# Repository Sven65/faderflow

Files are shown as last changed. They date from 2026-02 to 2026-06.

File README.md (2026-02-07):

# faderflow

> Fluid control over your desktop audio

A hardware audio mixer with motorized faders, full-color displays, and automatic application detection.



## Features

- 🎛️ 5 motorized faders with position sensing
- 🖥️ 5x 1.54" color TFT displays (240x240)
- 🔄 Bidirectional sync between hardware and Windows
- 🎯 Automatic app detection
- 📄 Multi-page navigation
- 💾 SD card icon storage

## Hardware

- Arduino Mega 2560
- 5x Behringer X32 Motorized Faders
- 3x DRV8833 Motor Driver Boards
- 6x ST7789 TFT Displays (1.54", 240x240)
- 6x EC11 Rotary Encoders
- SD Card Module
- USB-C PD Power (5V 3A)

## Software Stack

- **Desktop:** Rust + iced
- **Firmware:** Arduino C++
- **Platform:** Windows (Linux planned)

## Quick Start
```bash
# Clone repo
git clone https://github.com/Sven65/faderflow.git

# Build desktop app
cd desktop
cargo build --release

# Flash firmware
# Open firmware/faderflow/faderflow.ino in Arduino IDE
```

## Status

🚧 **Work in Progress** - Hardware picked out, software in development

## License

MIT License - see [LICENSE](LICENSE)

## Acknowledgments

Inspired by [deej](https://github.com/omriharel/deej)

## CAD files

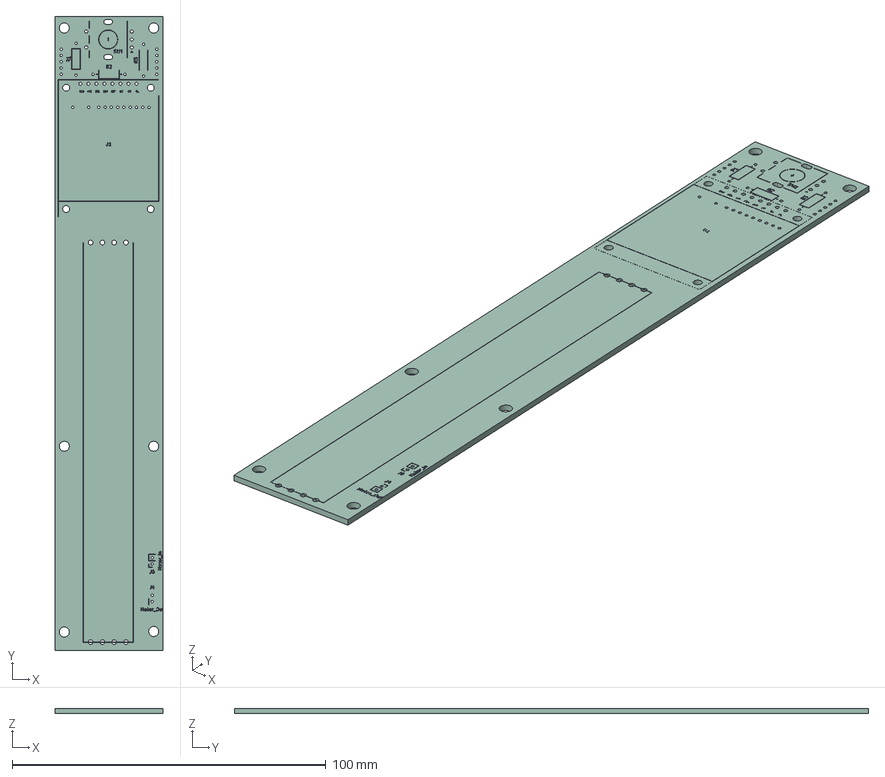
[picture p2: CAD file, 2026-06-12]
pcb/Channel/Channel.step
34.5 x 202.0 x 1.66 mm
Channel_silkscreen
Channel_PCB

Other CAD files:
pcb/Channel/Channel.stl

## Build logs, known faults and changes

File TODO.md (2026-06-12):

# FaderFlow - Project TODO

## ✅ Phase 0: Foundation (DONE)
- [x] Basic Iced UI setup
- [x] Windows audio session enumeration
- [x] Volume control (bidirectional sync)
- [x] Mute control (bidirectional sync)
- [x] App icon extraction
- [x] Cross-platform architecture (trait-based backend)
- [x] COM callback system for external changes
- [x] Batch processing to prevent UI jitter

## 🔨 Phase 1: Complete Audio Backend
- [ ] **Device Management**
    - [ ] Enumerate all audio output devices
    - [ ] Track which device each session is using (read-only for now)
    - [ ] Display device name in UI
    - [ ] System-wide default device switching
    - [ ] Detect when devices are plugged/unplugged

- [ ] **Session Management**
    - [ ] Handle sessions appearing/disappearing smoothly
    - [ ] Persist session-to-channel mappings
    - [ ] Auto-assign new sessions to free channels
    - [ ] Handle duplicate app names (Chrome tab 1, 2, 3...)

- [ ] **UI Polish**
    - [ ] Better layout (grid view for channels)
    - [ ] Visual feedback for which device is active
    - [ ] Session search/filter
    - [ ] Master volume control
    - [ ] System tray integration
    - [ ] Minimize to tray

## 🔌 Phase 2: Hardware Protocol
- [ ] **Serial Communication**
    - [ ] Define protocol format (JSON? Binary? MessagePack?)
    - [ ] Implement serial port detection/connection
    - [ ] Send motor position commands
        - [ ] Protocol: `MOTOR <channel> <position_0-100>`
    - [ ] Send screen update commands
        - [ ] Protocol: `SCREEN <channel> <icon_data> <name> <volume%>`
    - [ ] Receive fader position updates
        - [ ] Protocol: `FADER <channel> <position_0-100>`
    - [ ] Receive knob rotation updates
        - [ ] Protocol: `KNOB <channel> <delta>`

- [ ] **Motor Sync**
    - [ ] When Windows volume changes → move motor
    - [ ] Smooth motor movements (acceleration curves)
    - [ ] Handle motor conflicts (user moving while motor moves)
    - [ ] Calibration routine on startup

- [ ] **Screen Updates**
    - [ ] Convert icons to format your displays need (resolution, color depth)
    - [ ] Optimize icon transfer (only send when changed)
    - [ ] Handle missing icons (default placeholder)
    - [ ] Show volume percentage and mute status on screen

## 📊 Phase 3: Profile System
- [ ] **Profile Management**
    - [ ] Create profile structure (JSON config file?)
    - [ ] Save profiles: `profiles/<device_name>.json`
    - [ ] Profile contents:
        - [ ] Channel assignments (which app on which fader)
        - [ ] Custom names/colors per channel
        - [ ] Master volume settings
    - [ ] Auto-switch profile when output device changes
    - [ ] UI for creating/editing/deleting profiles
    - [ ] Import/export profiles

- [ ] **Channel Mapping**
    - [ ] Assign specific apps to specific channels
    - [ ] Wildcard matching (e.g., "chrome*" → channel 1)
    - [ ] Priority system (if multiple apps match)
    - [ ] "Unmapped apps" overflow handling

## 🎛️ Phase 4: Advanced Features
- [ ] **Per-App Audio Routing** (HARD)
    - [ ] Research options:
        - [ ] Study SoundSwitch source code
        - [ ] Study AudioRouter source code
        - [ ] Investigate IPolicyConfig COM interface
        - [ ] Consider app restart approach
    - [ ] Choose implementation strategy
    - [ ] Implement device switching
    - [ ] Handle edge cases (apps that don't respond)

- [ ] **Hotkeys**
    - [ ] Global hotkey support
    - [ ] Toggle mute for specific apps
    - [ ] Quick profile switching
    - [ ] Push-to-talk style muting

- [ ] **Advanced UI**
    - [ ] Dark/light theme
    - [ ] Customizable colors per channel
    - [ ] Visualizers (audio level meters)
    - [ ] Mini mode (compact overlay)
    - [ ] Always-on-top option

## 🐧 Phase 5: Cross-Platform (Future)
- [ ] **Linux Support**
    - [ ] PulseAudio backend implementation
    - [ ] PipeWire backend (modern Linux)
    - [ ] Icon extraction for Linux
    - [ ] Test on various distros

- [ ] **macOS Support** (maybe?)
    - [ ] CoreAudio backend implementation
    - [ ] Icon extraction for macOS
    - [ ] Handle macOS sandboxing/permissions

## 🔧 Phase 6: Polish & Release
- [ ] **Testing**
    - [ ] Test with many simultaneous apps
    - [ ] Test device hotplug scenarios
    - [ ] Test with different audio hardware
    - [ ] Memory leak testing (COM cleanup)
    - [ ] Long-running stability test

- [ ] **Documentation**
    - [ ] User guide
    - [ ] Hardware build guide
    - [ ] Protocol documentation
    - [ ] Firmware examples for Arduino/ESP32
    - [ ] Troubleshooting guide

- [ ] **Distribution**
    - [ ] Windows installer
    - [ ] Auto-updater
    - [ ] GitHub releases
    - [ ] AUR package (for Arch Linux)

## 🎯 Current Sprint
**Focus: Complete Phase 1 - Audio Backend**

### This Week:
1. Finish device enumeration in UI
2. Add device picker dropdown (read-only for now)
3. Implement session persistence between app restarts
4. Add system tray icon

### Next Week:
1. Start hardware protocol design
2. Set up serial communication testing
3. Mock hardware for development (simulate with keyboard?)

---

## Notes & Ideas
- Consider using `egui` instead of `iced` if you need faster iteration?
- Look into Windows MIDI API for ultra-low-latency control?
- Could add OBS integration (control audio sources)?
- Discord/TeamSpeak integration for per-person volume?
- Game detection (auto-load "Gaming" profile)?
- Time-based profiles (work hours vs evening)?

---

## Hardware Waiting On:
- [ ] Motorized faders (ordered)
- [ ] Screens (TFT? OLED? e-ink?)
- [ ] Rotary encoders for knobs
- [ ] Microcontroller (Arduino? ESP32? Teensy?)
- [ ] Case/enclosure design

---

**Keep this updated as you go!** 🚀

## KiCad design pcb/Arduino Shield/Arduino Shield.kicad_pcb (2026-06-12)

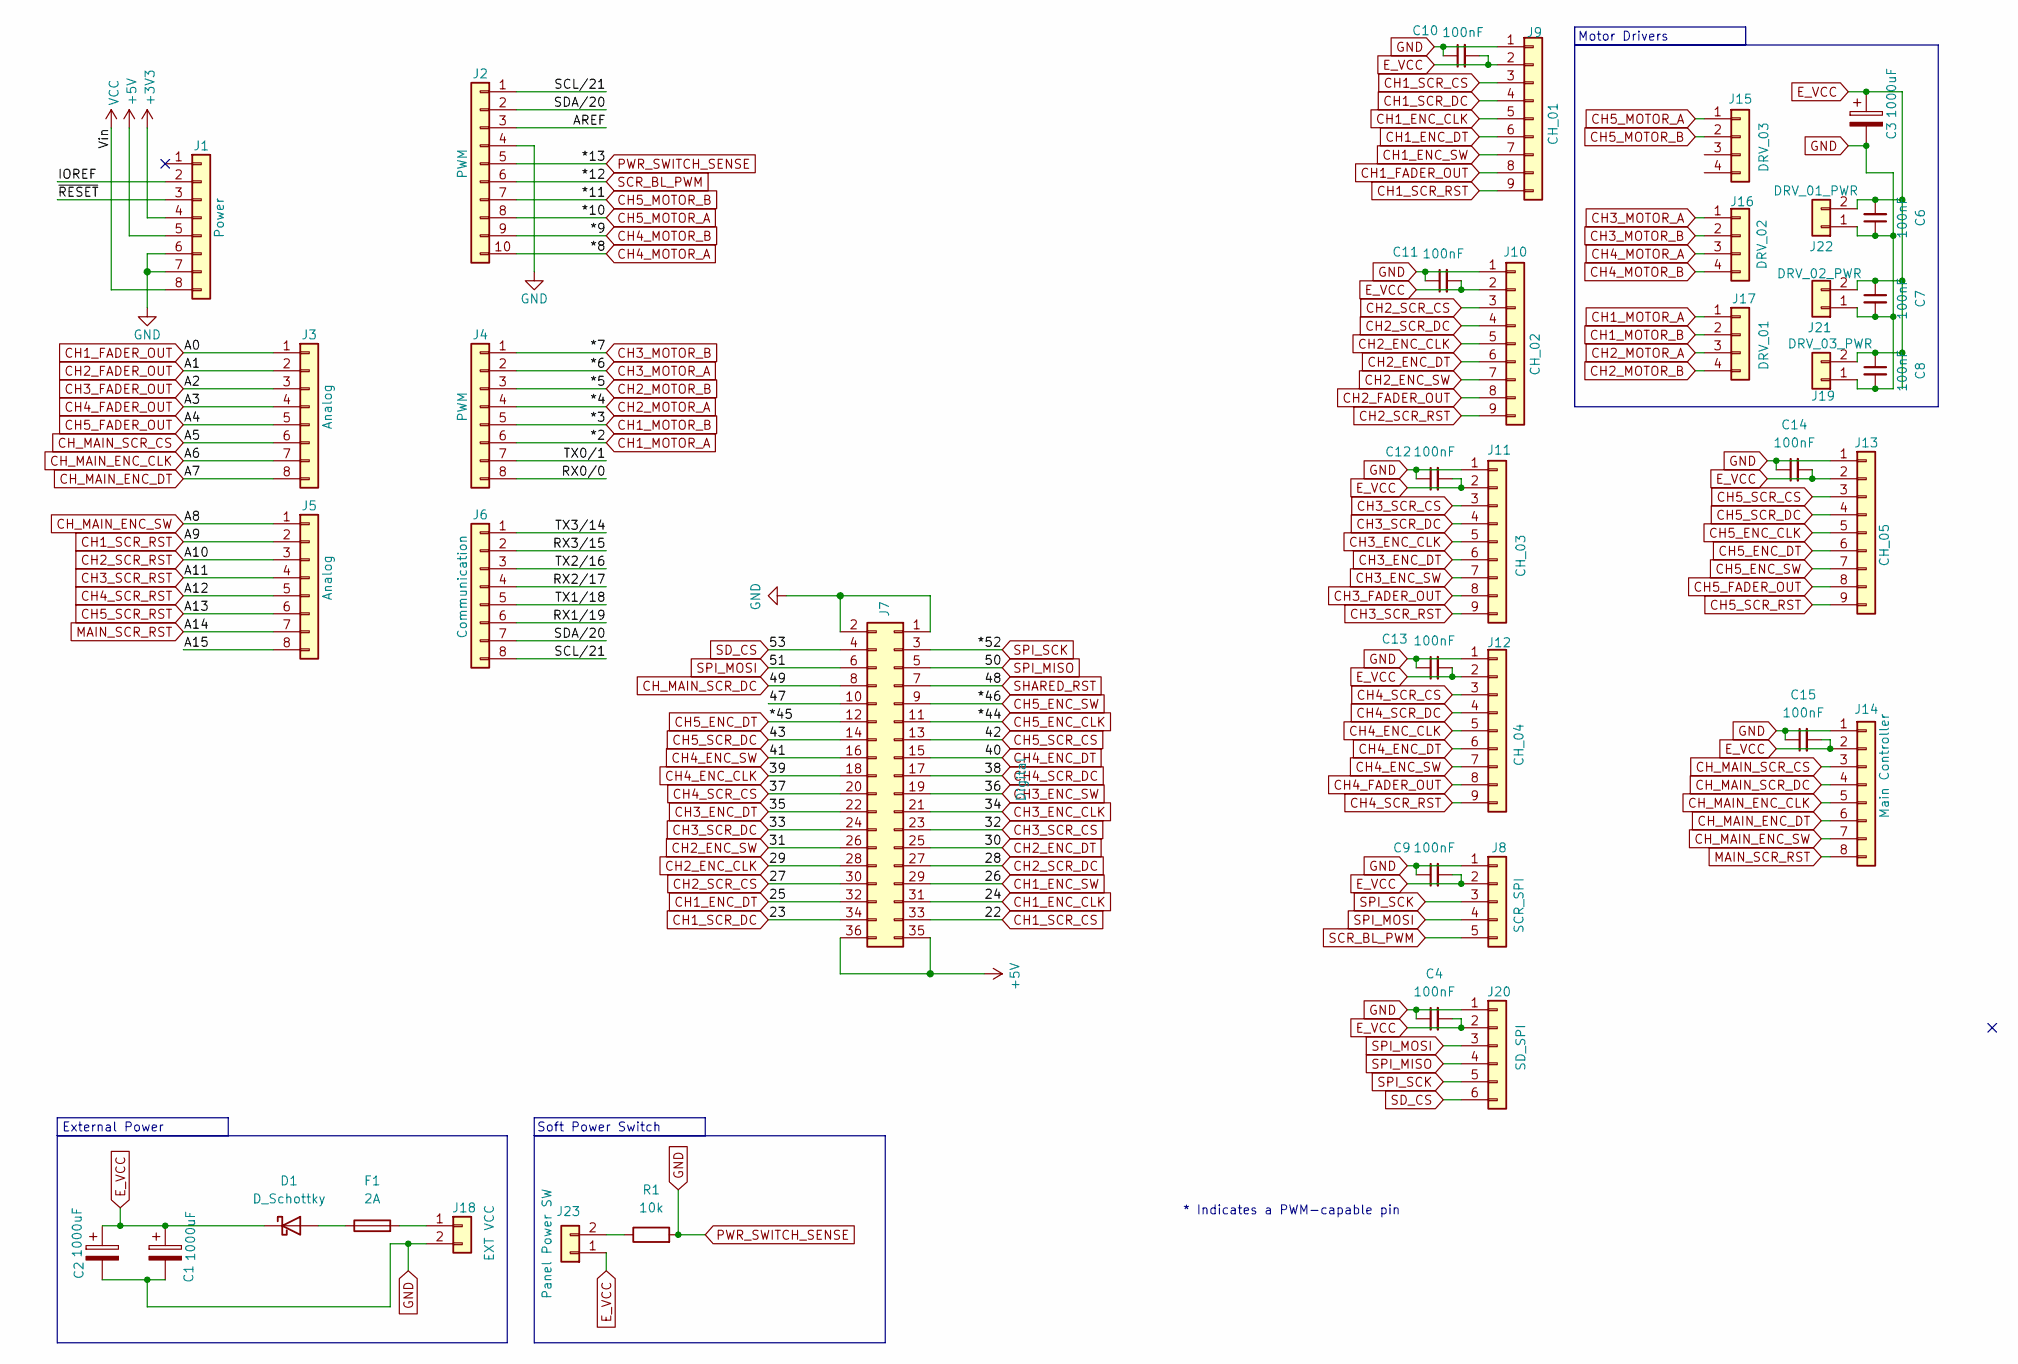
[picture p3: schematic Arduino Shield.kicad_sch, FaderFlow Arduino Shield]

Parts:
C1, C2, C3: 1000uF; CP_Radial_D8.0mm_P3.50mm
C4, C6, C7, C8, C9, C10, C11, C12, C13, C14, C15: 100nF; C_Disc_D5.0mm_W2.5mm_P5.00mm
D1: D_Schottky; D_DO-201AD_P15.24mm_Horizontal
F1: 2A; Fuseholder_Clip-5x20mm_Eaton_1A5601-01_Inline_P20.80x6.76mm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
J1: Power; PinSocket_1x08_P2.54mm_Vertical
J2: PWM; PinSocket_1x10_P2.54mm_Vertical
J3, J5: Analog; PinSocket_1x08_P2.54mm_Vertical
J4: PWM; PinSocket_1x08_P2.54mm_Vertical
J6: Communication; PinSocket_1x08_P2.54mm_Vertical
J7: Digital; PinSocket_2x18_P2.54mm_Vertical
J8: SCR_SPI; PinSocket_1x05_P2.00mm_Vertical
J9: CH_01; PinSocket_1x09_P2.00mm_Vertical
J10: CH_02; PinSocket_1x09_P2.00mm_Vertical
J11: CH_03; PinSocket_1x09_P2.00mm_Vertical
J12: CH_04; PinSocket_1x09_P2.00mm_Vertical
J13: CH_05; PinSocket_1x09_P2.00mm_Vertical
J14: Main Controller; PinSocket_1x08_P2.00mm_Vertical
J15: DRV_03; PinSocket_1x04_P2.00mm_Vertical
J16: DRV_02; PinSocket_1x04_P2.00mm_Vertical
J17: DRV_01; PinSocket_1x04_P2.00mm_Vertical
J18: EXT VCC; PinSocket_1x02_P2.00mm_Vertical
J19: DRV_03_PWR; PinSocket_1x02_P2.00mm_Vertical
J20: SD_SPI; PinSocket_1x06_P2.00mm_Vertical
J21: DRV_02_PWR; PinSocket_1x02_P2.00mm_Vertical
J22: DRV_01_PWR; PinSocket_1x02_P2.00mm_Vertical
J23: Panel Power SW; PinSocket_1x02_P2.00mm_Vertical
R1: 10k; R_Axial_DIN0207_L6.3mm_D2.5mm_P10.16mm_Horizontal

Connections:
+3V3: J1.4
+5V: J1.5, J7.35, J7.36
/47: J7.10
/A15: J5.8
/AREF: J2.3
/IOREF: J1.2
/RX0/0: J4.8
/RX1/19: J6.6
/RX2/17: J6.4
/RX3/15: J6.2
/SCL/21: J2.1, J6.8
/SDA/20: J2.2, J6.7
/TX0/1: J4.7
/TX1/18: J6.5
/TX2/16: J6.3
/TX3/14: J6.1
/~RESET: J1.3
CH1_ENC_CLK: J7.31, J9.5
CH1_ENC_DT: J7.32, J9.6
CH1_ENC_SW: J7.29, J9.7
CH1_FADER_OUT: J3.1, J9.8
CH1_MOTOR_A: J4.6, J17.1
CH1_MOTOR_B: J4.5, J17.2
CH1_SCR_CS: J7.33, J9.3
CH1_SCR_DC: J7.34, J9.4
CH1_SCR_RST: J5.2, J9.9
CH2_ENC_CLK: J7.28, J10.5
CH2_ENC_DT: J7.25, J10.6
CH2_ENC_SW: J7.26, J10.7
CH2_FADER_OUT: J3.2, J10.8
CH2_MOTOR_A: J4.4, J17.3
CH2_MOTOR_B: J4.3, J17.4
CH2_SCR_CS: J7.30, J10.3
CH2_SCR_DC: J7.27, J10.4
CH2_SCR_RST: J5.3, J10.9
CH3_ENC_CLK: J7.21, J11.5
CH3_ENC_DT: J7.22, J11.6
CH3_ENC_SW: J7.19, J11.7
CH3_FADER_OUT: J3.3, J11.8
CH3_MOTOR_A: J4.2, J16.1
CH3_MOTOR_B: J4.1, J16.2
CH3_SCR_CS: J7.23, J11.3
CH3_SCR_DC: J7.24, J11.4
CH3_SCR_RST: J5.4, J11.9
CH4_ENC_CLK: J7.18, J12.5
CH4_ENC_DT: J7.15, J12.6
CH4_ENC_SW: J7.16, J12.7
CH4_FADER_OUT: J3.4, J12.8
CH4_MOTOR_A: J2.10, J16.3
CH4_MOTOR_B: J2.9, J16.4
CH4_SCR_CS: J7.20, J12.3
CH4_SCR_DC: J7.17, J12.4
CH4_SCR_RST: J5.5, J12.9
CH5_ENC_CLK: J7.11, J13.5
CH5_ENC_DT: J7.12, J13.6
CH5_ENC_SW: J7.9, J13.7
CH5_FADER_OUT: J3.5, J13.8
CH5_MOTOR_A: J2.8, J15.1
CH5_MOTOR_B: J2.7, J15.2
CH5_SCR_CS: J7.13, J13.3
CH5_SCR_DC: J7.14, J13.4
CH5_SCR_RST: J5.6, J13.9
CH_MAIN_ENC_CLK: J3.7, J14.5
CH_MAIN_ENC_DT: J3.8, J14.6
CH_MAIN_ENC_SW: J5.1, J14.7
CH_MAIN_SCR_CS: J3.6, J14.3
CH_MAIN_SCR_DC: J7.8, J14.4
E_VCC: C1.1, C2.1, C3.1, C4.2, C6.2, C7.1, C8.1, C9.2, C10.2, C11.2, C12.2, C13.2, C14.2, C15.2, D1.1 (K), J8.2, J9.2, J10.2, J11.2, J12.2, J13.2, J14.2, J19.2, J20.2, J21.2, J22.2, J23.1
GND: C1.2, C2.2, C3.2, C4.1, C6.1, C7.2, C8.2, C9.1, C10.1, C11.1, C12.1, C13.1, C14.1, C15.1, J1.6, J1.7, J2.4, J2.5, J7.1, J7.2, J8.1, J9.1, J10.1, J11.1, J12.1, J13.1, J14.1, J18.2, J19.1, J20.1, J21.1, J22.1, R1.2
MAIN_SCR_RST: J5.7, J14.8
unnamed: D1.2 (A), F1.1
unnamed: F1.2, J18.1
unnamed: J23.2, R1.1
SCR_BL_PWM: J2.6, J8.5
SD_CS: J7.4, J20.6
SHARED_RST: J7.7
SPI_MISO: J7.5, J20.4
SPI_MOSI: J7.6, J8.4, J20.3
SPI_SCK: J7.3, J8.3, J20.5
VCC: J1.8

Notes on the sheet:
External Power
Soft Power Switch
Motor Drivers
* Indicates a PWM-capable pin

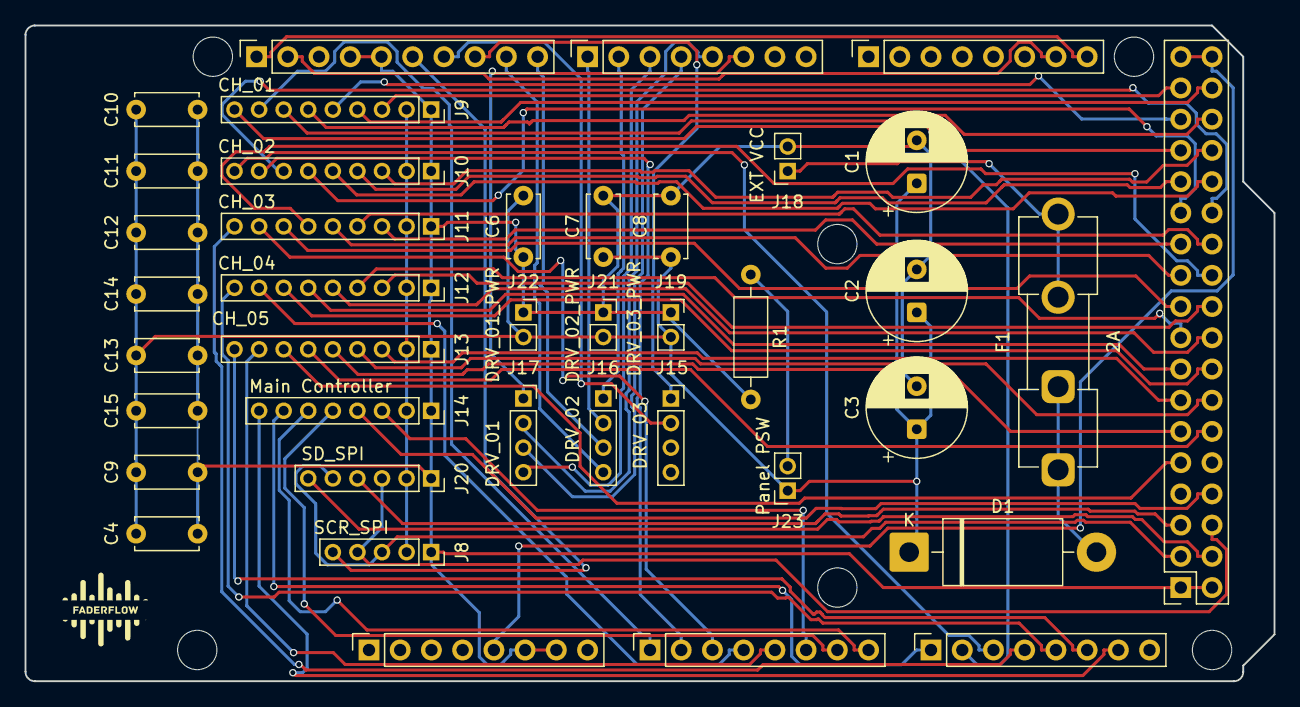
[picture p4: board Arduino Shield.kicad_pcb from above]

Board: 2 copper layers, 101.6 x 53.3 mm, 46 parts (0 on the bottom side), 64 nets.

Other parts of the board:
MH1, MH2, MH3, MH4, MH5, MH6: MountingHole_3.2mm

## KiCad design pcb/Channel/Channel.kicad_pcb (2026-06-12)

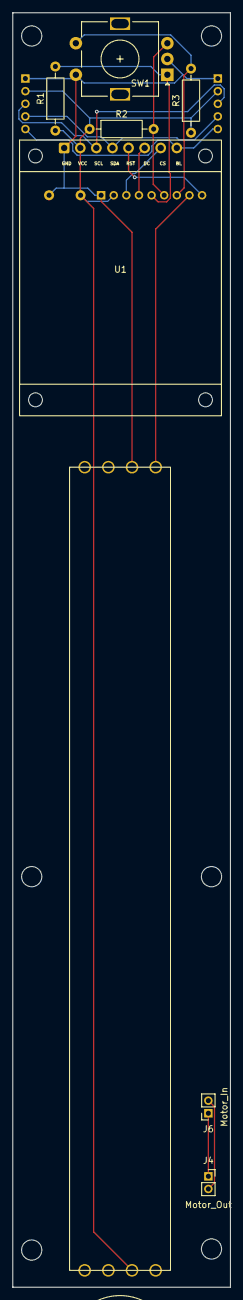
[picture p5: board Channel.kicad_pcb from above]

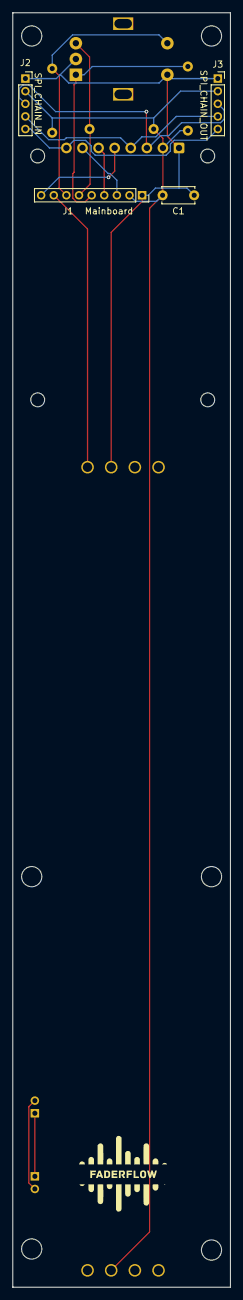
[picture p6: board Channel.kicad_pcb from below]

Board: 2 copper layers, 34.5 x 202.0 mm, 18 parts (4 on the bottom side), 14 nets.

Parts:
C1: 0.1uF; C_Disc_D5.0mm_W2.5mm_P5.00mm
F1: Behringer X32 Fader
J1: Mainboard; PinSocket_1x09_P2.00mm_Vertical
J2: SPI_CHAIN_IN; PinSocket_1x05_P2.00mm_Vertical
J3: SPI_CHAIN_OUT; PinSocket_1x05_P2.00mm_Vertical
J4: Motor_Out; PinSocket_1x02_P2.00mm_Vertical
J6: Motor_In; PinSocket_1x02_P2.00mm_Vertical
Mount_1, Mount_2, Mount_3, Mount_4, Mount_6, Mount_7: MountingHole_3.2mm_M3
R1, R2, R3: 10k; R_Axial_DIN0207_L6.3mm_D2.5mm_P10.16mm_Horizontal
SW1: RotaryEncoder_Switch; RotaryEncoder_Alps_EC11E-Switch_Vertical_H20mm
U1: 1.54 inch

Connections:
ENC_CLK: J1.5, R1.2, SW1.A
ENC_DT: J1.6, R2.2, SW1.B
ENC_SW: J1.7, R3.2, SW1.S1
E_VCC: C1.2, F1.3 (T2), J1.2, J2.2, J3.2, R1.1, R2.1, R3.1, U1.2 (VCC)
FADER_OUT: F1.2 (W), J1.8
GND: C1.1, F1.1 (T1), J1.1, J2.1, J3.1, SW1.C, SW1.S2, U1.1 (GND)
MOTOR+: J4.1, J6.1
MOTOR-: J4.2, J6.2
SCREEN_CS: J1.3, U1.7 (CS)
SCREEN_DC: J1.4, U1.6 (DC)
SCREEN_RST: J1.9, U1.5 (RST)
SCR_BL_PWM: J2.5, J3.5, U1.8 (BL)
SPI_MOSI: J2.4, J3.4, U1.4 (SDA)
SPI_SCK: J2.3, J3.3, U1.3 (SCL)

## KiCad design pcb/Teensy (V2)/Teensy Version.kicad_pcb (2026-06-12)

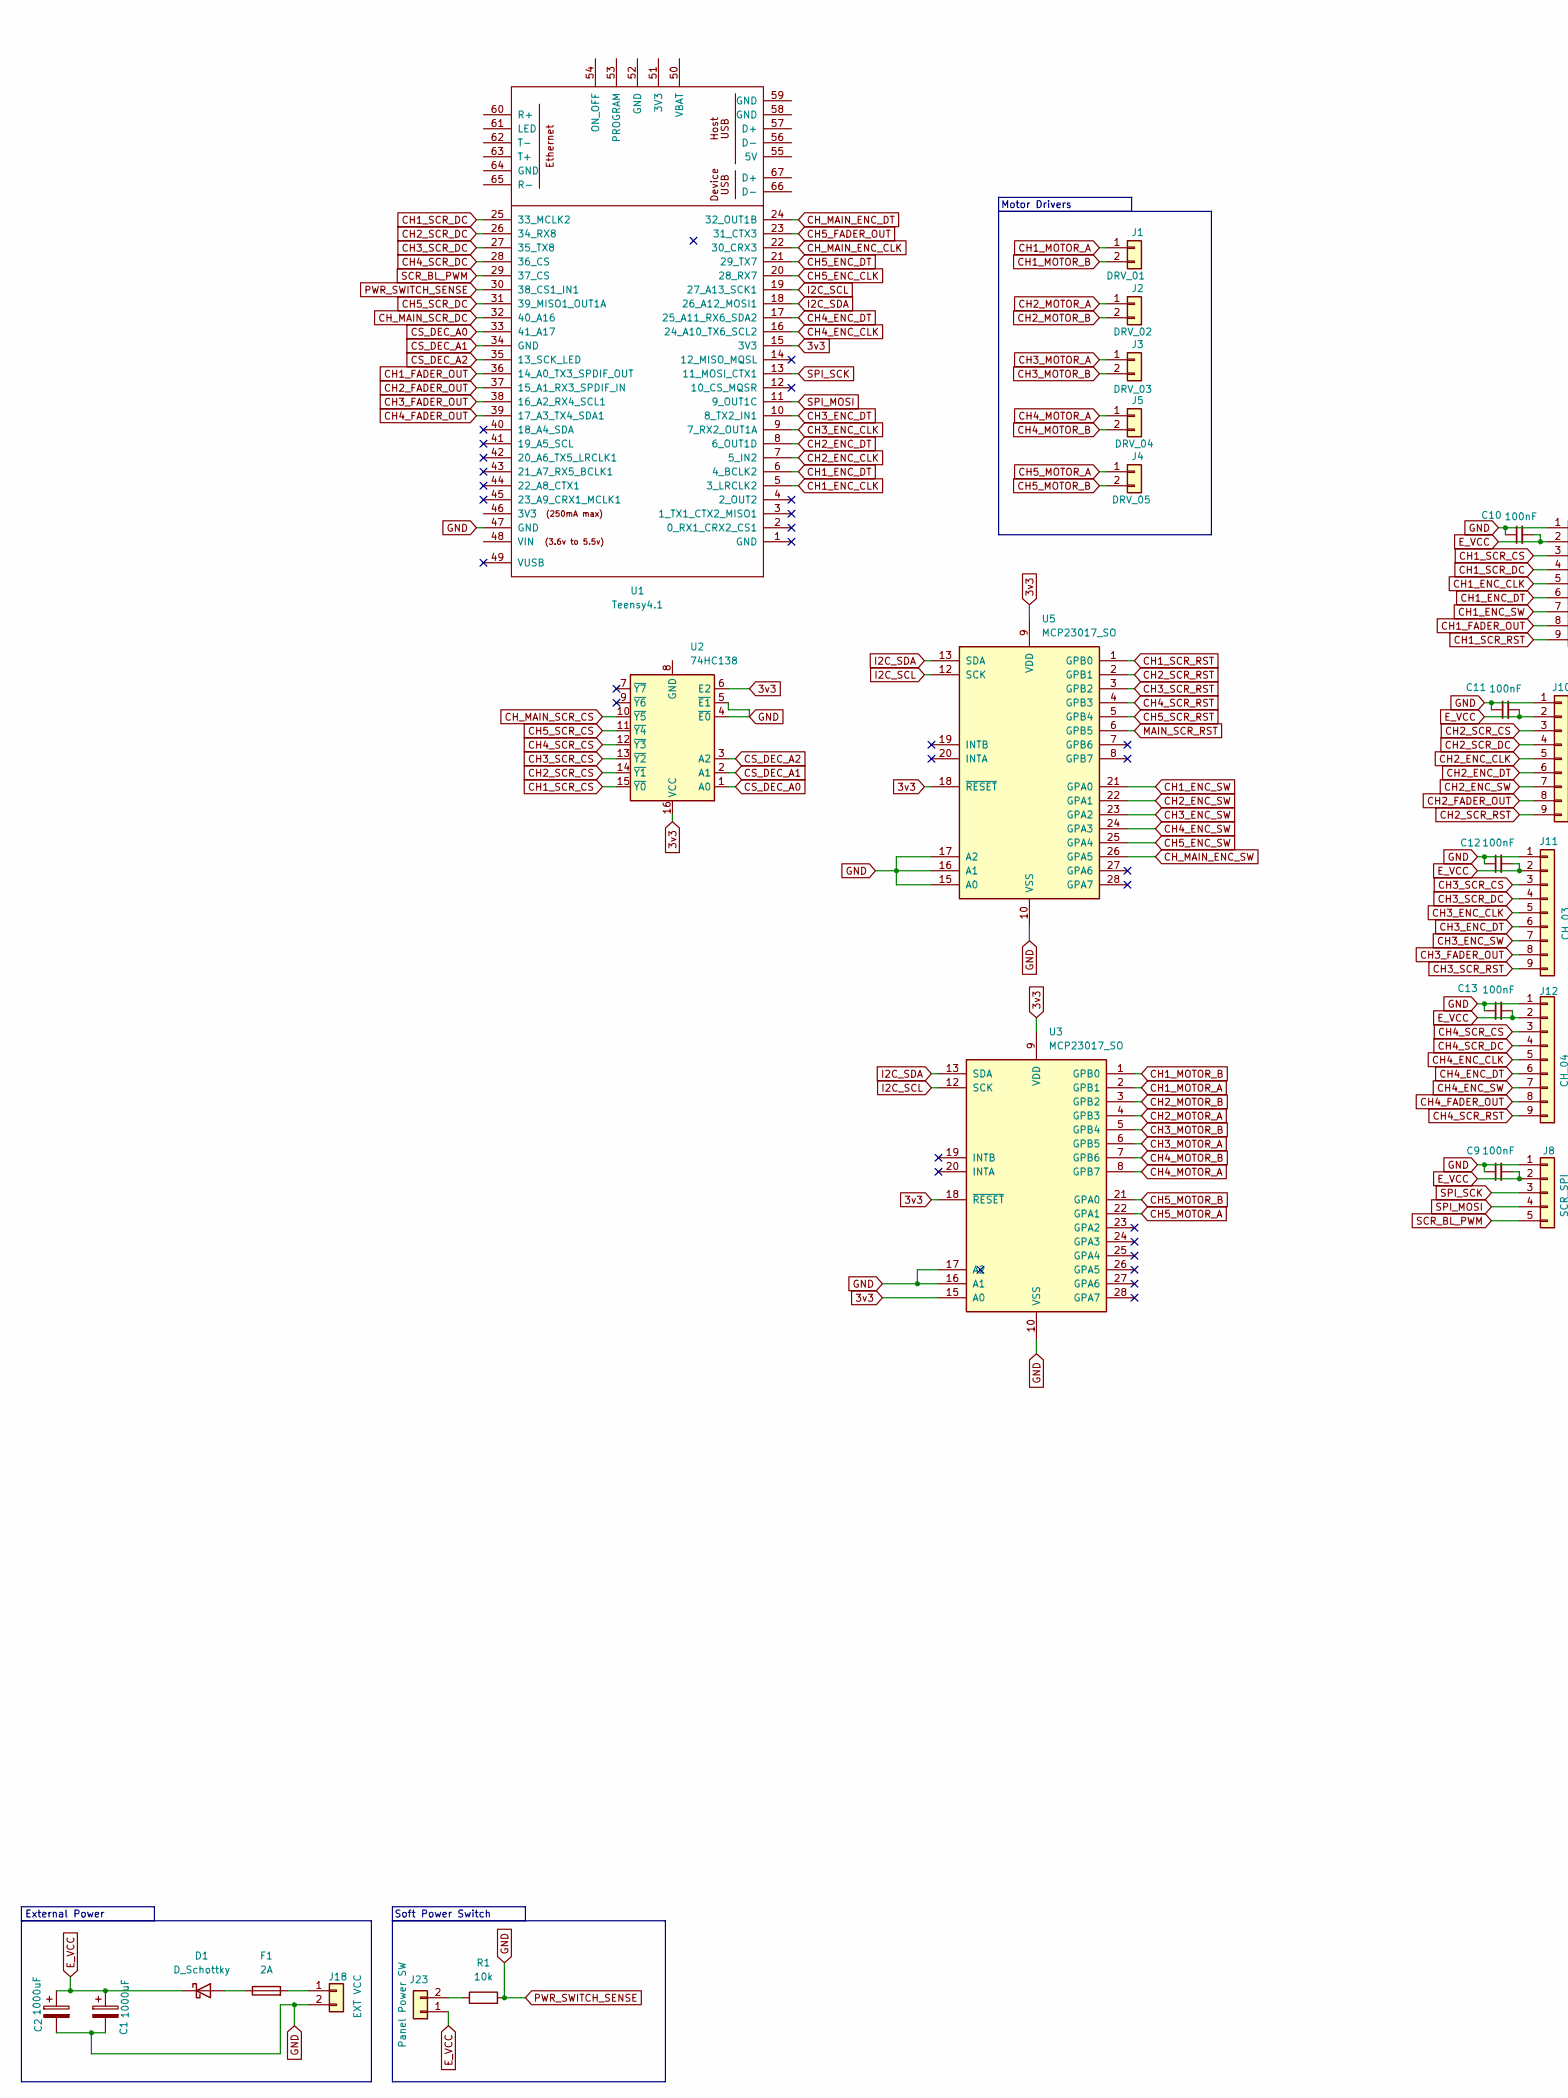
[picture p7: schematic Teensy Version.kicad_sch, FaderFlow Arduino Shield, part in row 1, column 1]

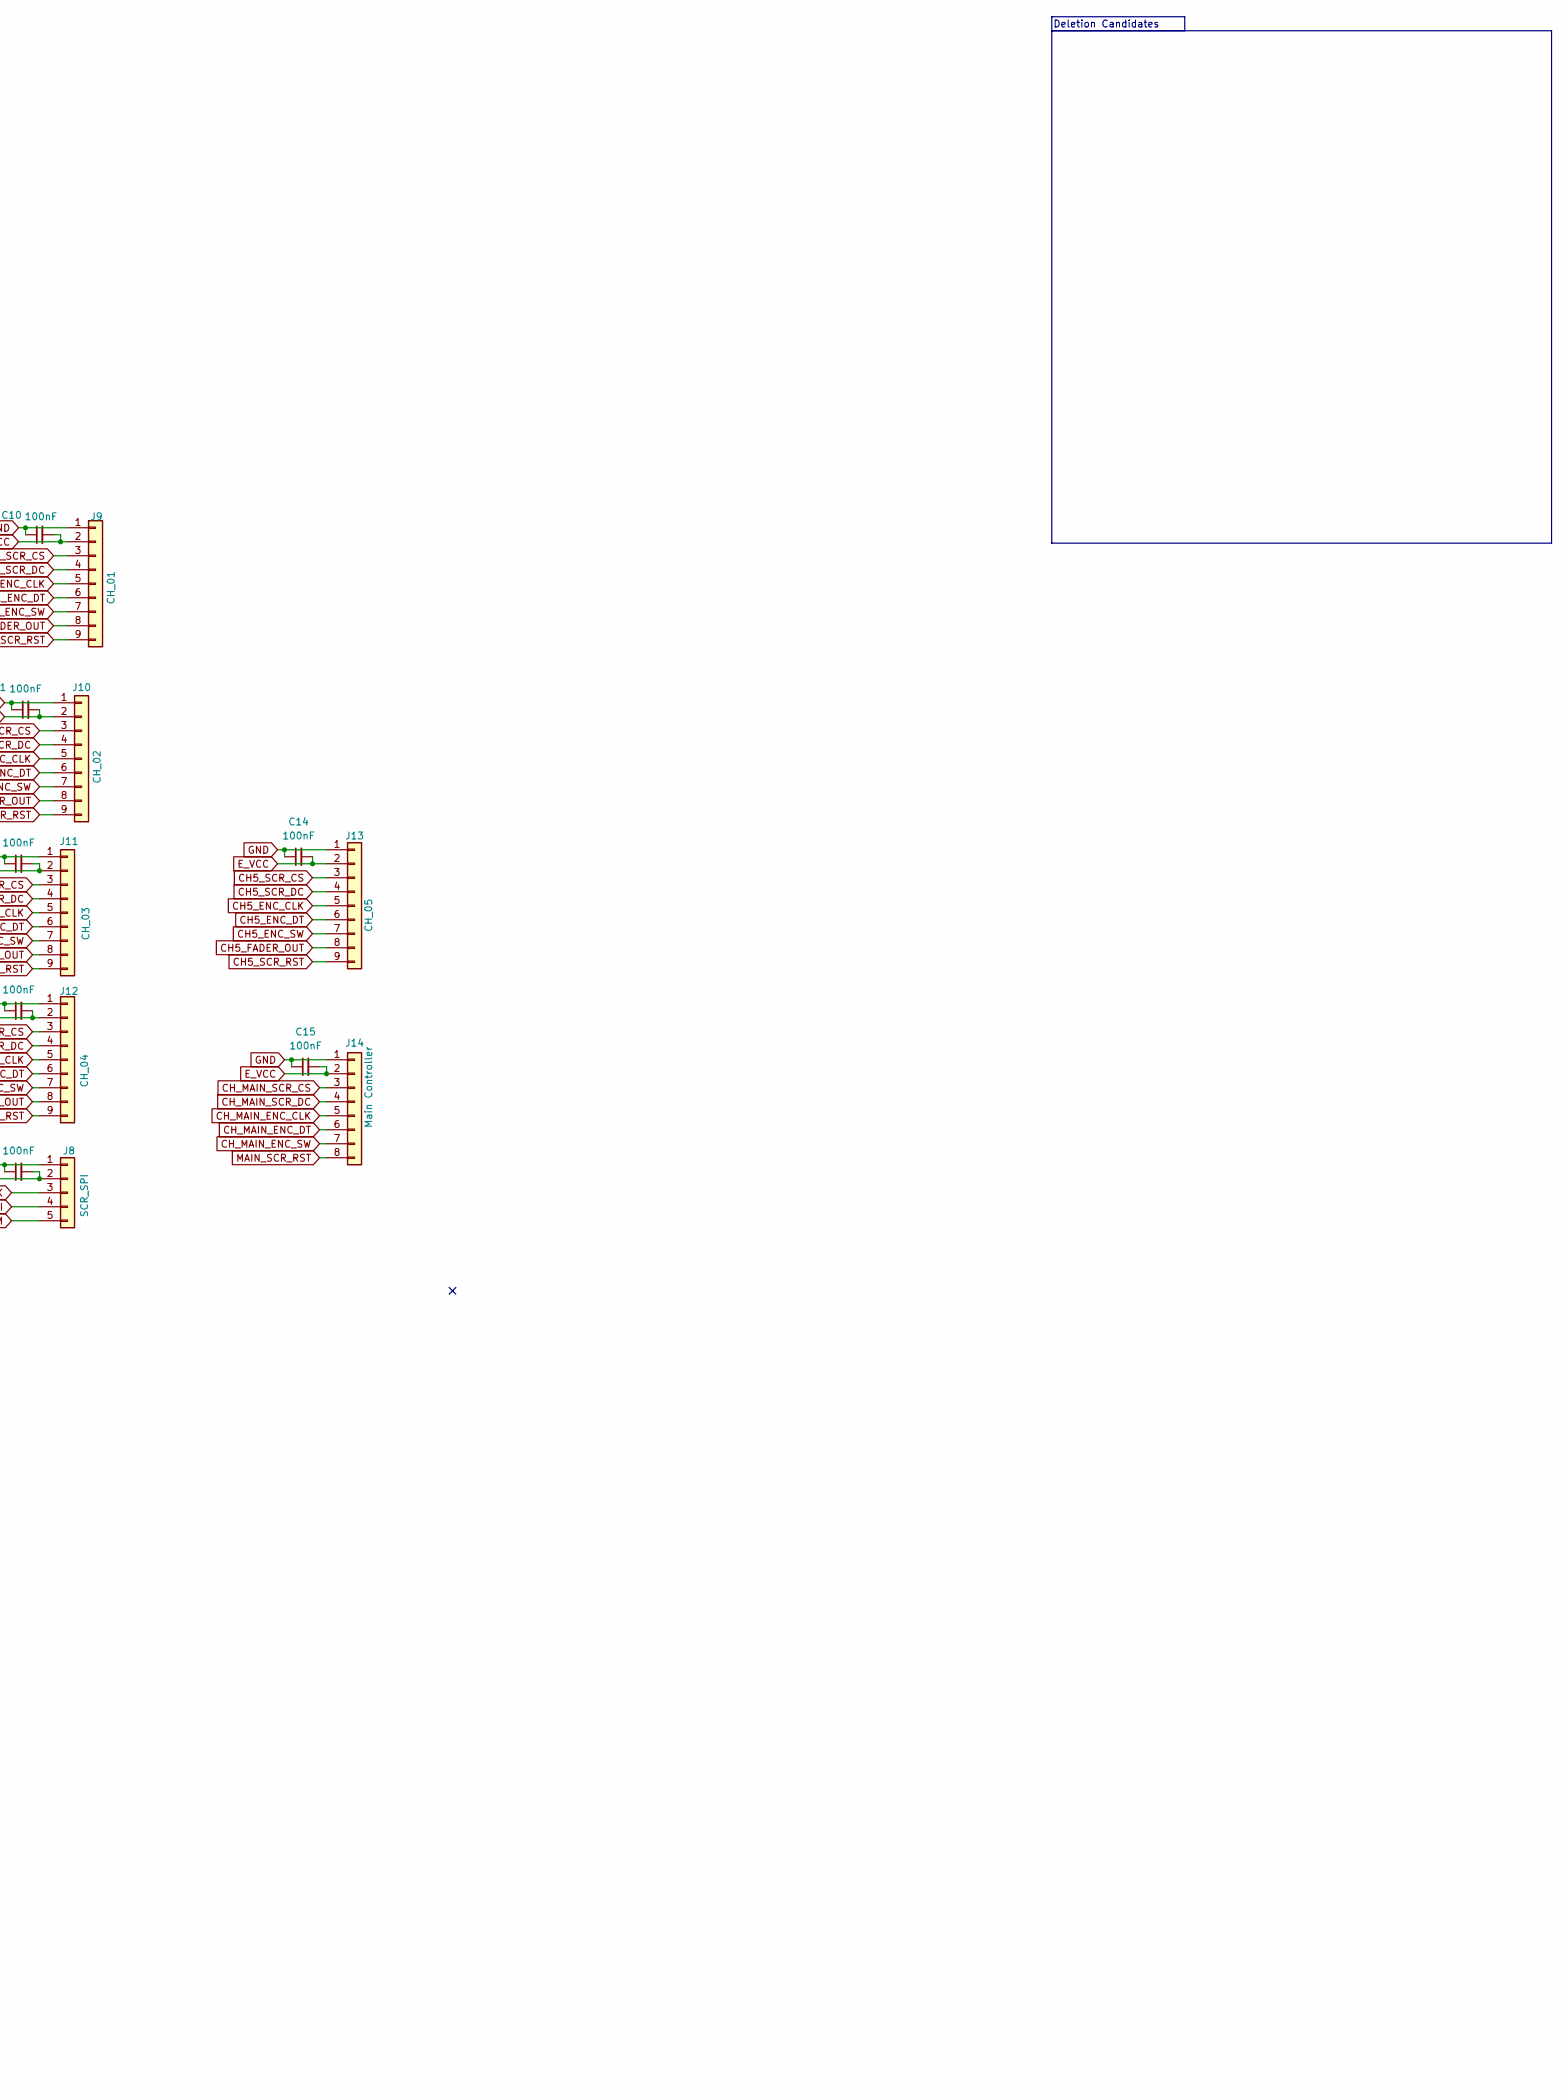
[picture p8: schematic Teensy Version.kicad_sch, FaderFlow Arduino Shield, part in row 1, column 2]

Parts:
C1, C2: 1000uF; CP_Radial_D8.0mm_P3.50mm
C9, C10, C11, C12, C13, C14, C15: 100nF; C_Disc_D5.0mm_W2.5mm_P5.00mm
D1: D_Schottky; D_DO-201AD_P15.24mm_Horizontal
F1: 2A; Fuseholder_Clip-5x20mm_Eaton_1A5601-01_Inline_P20.80x6.76mm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
J1: DRV_01; PinSocket_1x02_P2.00mm_Vertical
J2: DRV_02; PinSocket_1x02_P2.00mm_Vertical
J3: DRV_03; PinSocket_1x02_P2.00mm_Vertical
J4: DRV_05; PinSocket_1x02_P2.00mm_Vertical
J5: DRV_04; PinSocket_1x02_P2.00mm_Vertical
J8: SCR_SPI; PinSocket_1x05_P2.00mm_Vertical
J9: CH_01; PinSocket_1x09_P2.00mm_Vertical
J10: CH_02; PinSocket_1x09_P2.00mm_Vertical
J11: CH_03; PinSocket_1x09_P2.00mm_Vertical
J12: CH_04; PinSocket_1x09_P2.00mm_Vertical
J13: CH_05; PinSocket_1x09_P2.00mm_Vertical
J14: Main Controller; PinSocket_1x08_P2.00mm_Vertical
J18: EXT VCC; PinSocket_1x02_P2.00mm_Vertical
J23: Panel Power SW; PinSocket_1x02_P2.00mm_Vertical
R1: 10k; R_Axial_DIN0207_L6.3mm_D2.5mm_P10.16mm_Horizontal
U1: Teensy4.1; Teensy41
U2: 74HC138; SO-16_3.9x9.9mm_P1.27mm
U3, U5: MCP23017_SO; SOIC-28W_7.5x17.9mm_P1.27mm

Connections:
3v3: U1.15 (3V3), U2.6 (E2), U2.16 (VCC), U3.9 (VDD), U3.15 (A0), U3.18 (~RESET), U5.9 (VDD), U5.18 (~RESET)
CH1_ENC_CLK: J9.5, U1.5 (3_LRCLK2)
CH1_ENC_DT: J9.6, U1.6 (4_BCLK2)
CH1_ENC_SW: J9.7, U5.21 (GPA0)
CH1_FADER_OUT: J9.8, U1.36 (14_A0_TX3_SPDIF_OUT)
CH1_MOTOR_A: J1.1, U3.2 (GPB1)
CH1_MOTOR_B: J1.2, U3.1 (GPB0)
CH1_SCR_CS: J9.3, U2.15 (~Y0)
CH1_SCR_DC: J9.4, U1.25 (33_MCLK2)
CH1_SCR_RST: J9.9, U5.1 (GPB0)
CH2_ENC_CLK: J10.5, U1.7 (5_IN2)
CH2_ENC_DT: J10.6, U1.8 (6_OUT1D)
CH2_ENC_SW: J10.7, U5.22 (GPA1)
CH2_FADER_OUT: J10.8, U1.37 (15_A1_RX3_SPDIF_IN)
CH2_MOTOR_A: J2.1, U3.4 (GPB3)
CH2_MOTOR_B: J2.2, U3.3 (GPB2)
CH2_SCR_CS: J10.3, U2.14 (~Y1)
CH2_SCR_DC: J10.4, U1.26 (34_RX8)
CH2_SCR_RST: J10.9, U5.2 (GPB1)
CH3_ENC_CLK: J11.5, U1.9 (7_RX2_OUT1A)
CH3_ENC_DT: J11.6, U1.10 (8_TX2_IN1)
CH3_ENC_SW: J11.7, U5.23 (GPA2)
CH3_FADER_OUT: J11.8, U1.38 (16_A2_RX4_SCL1)
CH3_MOTOR_A: J3.1, U3.6 (GPB5)
CH3_MOTOR_B: J3.2, U3.5 (GPB4)
CH3_SCR_CS: J11.3, U2.13 (~Y2)
CH3_SCR_DC: J11.4, U1.27 (35_TX8)
CH3_SCR_RST: J11.9, U5.3 (GPB2)
CH4_ENC_CLK: J12.5, U1.16 (24_A10_TX6_SCL2)
CH4_ENC_DT: J12.6, U1.17 (25_A11_RX6_SDA2)
CH4_ENC_SW: J12.7, U5.24 (GPA3)
CH4_FADER_OUT: J12.8, U1.39 (17_A3_TX4_SDA1)
CH4_MOTOR_A: J5.1, U3.8 (GPB7)
CH4_MOTOR_B: J5.2, U3.7 (GPB6)
CH4_SCR_CS: J12.3, U2.12 (~Y3)
CH4_SCR_DC: J12.4, U1.28 (36_CS)
CH4_SCR_RST: J12.9, U5.4 (GPB3)
CH5_ENC_CLK: J13.5, U1.20 (28_RX7)
CH5_ENC_DT: J13.6, U1.21 (29_TX7)
CH5_ENC_SW: J13.7, U5.25 (GPA4)
CH5_FADER_OUT: J13.8, U1.23 (31_CTX3)
CH5_MOTOR_A: J4.1, U3.22 (GPA1)
CH5_MOTOR_B: J4.2, U3.21 (GPA0)
CH5_SCR_CS: J13.3, U2.11 (~Y4)
CH5_SCR_DC: J13.4, U1.31 (39_MISO1_OUT1A)
CH5_SCR_RST: J13.9, U5.5 (GPB4)
CH_MAIN_ENC_CLK: J14.5, U1.22 (30_CRX3)
CH_MAIN_ENC_DT: J14.6, U1.24 (32_OUT1B)
CH_MAIN_ENC_SW: J14.7, U5.26 (GPA5)
CH_MAIN_SCR_CS: J14.3, U2.10 (~Y5)
CH_MAIN_SCR_DC: J14.4, U1.32 (40_A16)
CS_DEC_A0: U1.33 (41_A17), U2.1 (A0)
CS_DEC_A1: U1.34 (GND), U2.2 (A1)
CS_DEC_A2: U1.35 (13_SCK_LED), U2.3 (A2)
E_VCC: C1.1, C2.1, C9.2, C10.2, C11.2, C12.2, C13.2, C14.2, C15.2, D1.1 (K), J8.2, J9.2, J10.2, J11.2, J12.2, J13.2, J14.2, J23.1
GND: C1.2, C2.2, C9.1, C10.1, C11.1, C12.1, C13.1, C14.1, C15.1, J8.1, J9.1, J10.1, J11.1, J12.1, J13.1, J14.1, J18.2, R1.2, U1.30 (38_CS1_IN1), U1.47 (GND), U2.4 (~E0), U2.5 (~E1), U3.10 (VSS), U3.16 (A1), U3.17 (A2), U5.10 (VSS), U5.15 (A0), U5.16 (A1), U5.17 (A2)
I2C_SCL: U1.19 (27_A13_SCK1), U3.12 (SCK), U5.12 (SCK)
I2C_SDA: U1.18 (26_A12_MOSI1), U3.13 (SDA), U5.13 (SDA)
MAIN_SCR_RST: J14.8, U5.6 (GPB5)
unnamed: D1.2 (A), F1.1
unnamed: F1.2, J18.1
unnamed: J23.2, R1.1
SCR_BL_PWM: J8.5, U1.29 (37_CS)
SPI_MOSI: J8.4, U1.11 (9_OUT1C)
SPI_SCK: J8.3, U1.13 (11_MOSI_CTX1)

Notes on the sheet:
External Power
Deletion Candidates
Soft Power Switch
Motor Drivers

Board: 2 copper layers, 30 parts (0 on the bottom side), 65 nets, no tracks yet.

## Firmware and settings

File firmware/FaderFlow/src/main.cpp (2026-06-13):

//
// Created by Mackan on 2026-06-12.
// FaderFlow main — 5 channels, non-blocking serial parser, icon streaming.
//

#include "main.h"
#include <SPI.h>
#include <EEPROM.h>
#include "protocol.h"
#include "utils/device_id.h"
#include "utils/comms.h"
#include "channel.h"

#define NUM_CHANNELS 5
#define NUM_CONNECTED_CHANNELS 5
#define BL_PIN 12
#define SS_PIN 53

// Per-channel pin tables (Mega). Each channel owns a 5-pin digital block:
// CS, DC, CLK, DT, SW — then RST on A9-A13.
const int8_t  CS_PINS[NUM_CHANNELS]   = { 22, 27, 32, 37, 42 };
const int8_t  DC_PINS[NUM_CHANNELS]   = { 23, 28, 33, 38, 43 };
const int8_t  RST_PINS[NUM_CHANNELS]  = { 63, 64, 65, 66, 67 };  // A9-A13
const uint8_t ENC_CLK[NUM_CHANNELS]   = { 24, 29, 34, 39, 44 };
const uint8_t ENC_DT[NUM_CHANNELS]    = { 25, 30, 35, 40, 45 };
const uint8_t ENC_SW[NUM_CHANNELS]    = { 26, 31, 36, 41, 46 };
const uint8_t MOTOR_A[NUM_CHANNELS]   = { 2, 4, 6, 8, 10 };      // all PWM
const uint8_t MOTOR_B[NUM_CHANNELS]   = { 3, 5, 7, 9, 11 };
const uint8_t FADER_PIN[NUM_CHANNELS] = { A0, A1, A2, A3, A4 };

Channel* channels[NUM_CHANNELS];

static bool handshakeComplete = false;

// ---- Outgoing ----

// Protocol speaks 0-255 for fader position; channels speak 0-100
static uint8_t volumeToProtocol(int volume) {
  return map(volume, 0, 100, 0, 255);
}

static void sendFaderUpdate(uint8_t channel, int volume) {
  FaderMessage msg;
  msg.cmd = CMD_FADER_UPDATE;
  msg.channel = channel;
  msg.position = volumeToProtocol(volume);
  Serial.write((uint8_t*)&msg, sizeof(msg));
}


// ---- Calibration ----
//
// Started by the host (CMD_CALIBRATION_START). For each channel in turn:
// pull the fader to the bottom, press its encoder knob, push it to the
// top, press again. Raw ADC ranges go to EEPROM and load at boot.

#define CAL_EEPROM_ADDR 32   // UUID lives at 0-16; plenty of clearance
#define CAL_EEPROM_MAGIC 0xCA

static bool calMode = false;
static uint8_t calChannel = 0;
static uint8_t calPhase = 0;  // 0 = waiting bottom, 1 = waiting top
static uint16_t calMinArr[NUM_CHANNELS];
static uint16_t calMaxArr[NUM_CHANNELS];
static uint16_t calBottomRaw = 0;            // bottom capture, echoed on the TOP prompt
static char     calMsg[NUM_CHANNELS][22];    // per-channel result, shown on the Done screen

static void sendCalStatus(uint8_t channel, uint8_t phase) {
  uint8_t msg[3] = { CMD_CALIBRATION_STATUS, channel, phase };
  Serial.write(msg, 3);
}

// Raw calibration values for the host's debug panel.
// kind 0 = bottom captured (v1=bottom raw); kind 1 = accepted (v1=min, v2=max);
// kind 2 = rejected (v1=travel). u16 sent little-endian.
static void sendCalDebug(uint8_t channel, uint8_t kind, uint16_t v1, uint16_t v2) {
  uint8_t msg[7] = {
    CMD_CALIBRATION_DEBUG, channel, kind,
    (uint8_t)(v1 & 0xFF), (uint8_t)(v1 >> 8),
    (uint8_t)(v2 & 0xFF), (uint8_t)(v2 >> 8)
  };
  Serial.write(msg, 7);
}

static void saveCalibration() {
  EEPROM.update(CAL_EEPROM_ADDR, CAL_EEPROM_MAGIC);
  int addr = CAL_EEPROM_ADDR + 1;
  for (uint8_t i = 0; i < NUM_CHANNELS; i++) {
    EEPROM.put(addr, calMinArr[i]); addr += 2;
    EEPROM.put(addr, calMaxArr[i]); addr += 2;
  }
}

static void loadCalibration() {
  for (uint8_t i = 0; i < NUM_CHANNELS; i++) {
    calMinArr[i] = FADER_RAW_MIN;
    calMaxArr[i] = FADER_RAW_MAX;
  }
  if (EEPROM.read(CAL_EEPROM_ADDR) != CAL_EEPROM_MAGIC) return;
  int addr = CAL_EEPROM_ADDR + 1;
  for (uint8_t i = 0; i < NUM_CHANNELS; i++) {
    uint16_t mn, mx;
    EEPROM.get(addr, mn); addr += 2;
    EEPROM.get(addr, mx); addr += 2;
    if (mx > mn && mx <= 1023 && (mx - mn) > 200) {
      calMinArr[i] = mn;
      calMaxArr[i] = mx;
      if (i < NUM_CONNECTED_CHANNELS) channels[i]->setFaderCalibration(mn, mx);
    }
  }
}

static void showCalScreen(uint8_t i) {
  if (i >= NUM_CONNECTED_CHANNELS) return;
  if (i < calChannel) {
    // Already calibrated: show this channel's captured result on screen
    channels[i]->showMessage("CALIBRATE", "Done!", calMsg[i]);
  } else if (i == calChannel) {
    if (calPhase == 0) {
      channels[i]->showMessage("CALIBRATE", "Fader to BOTTOM", "then press knob");
    } else {
      // Phase 1: echo the bottom value just captured so it can be eyeballed
      char l3[22];
      snprintf(l3, sizeof(l3), "btm=%u, press", (unsigned)calBottomRaw);
      channels[i]->showMessage("CALIBRATE", "Fader to TOP", l3);
    }
  } else {
    channels[i]->showMessage("CALIBRATE", "Waiting...", nullptr);
  }
}

static void startCalibration() {
  // Coast, not brake -- the user must hand-position each fader against the
  // physical stops, and an electrical brake makes that stiff and unstable.
  for (uint8_t i = 0; i < NUM_CONNECTED_CHANNELS; i++) channels[i]->releaseFader();
  calMode = true;
  calChannel = 0;
  calPhase = 0;
  for (uint8_t i = 0; i < NUM_CONNECTED_CHANNELS; i++) showCalScreen(i);
  sendCalStatus(0, 0);
}

static void exitCalibration(uint8_t statusPhase) {
  calMode = false;
  for (uint8_t i = 0; i < NUM_CONNECTED_CHANNELS; i++) {
    channels[i]->flushInputs();   // discard knob twiddling during cal
    channels[i]->releaseFader();  // coast so faders stay hand-movable until host re-seeks
    channels[i]->redrawUI();
  }
  sendCalStatus(0, statusPhase);  // host re-syncs names/icons/volumes
}

static void cancelCalibration() {
  if (!calMode) return;
  loadCalibration();  // discard partial captures, restore saved values
  exitCalibration(3);
}

static void runCalibration() {
  for (uint8_t i = 0; i < NUM_CONNECTED_CHANNELS; i++) {
    channels[i]->pollEncoderButton();
  }

  bool pressed = false;
  for (uint8_t i = 0; i < NUM_CONNECTED_CHANNELS; i++) {
    if (channels[i]->wasButtonPressed()) pressed = true;
  }


  if (!pressed) return;

  if (calPhase == 0) {
    calBottomRaw = channels[calChannel]->faderRaw();
    sendCalDebug(calChannel, 0, calBottomRaw, 0);
    calPhase = 1;
    showCalScreen(calChannel);
    sendCalStatus(calChannel, 1);
  } else {
    uint16_t topRaw = channels[calChannel]->faderRaw();
    uint16_t mn = min(calBottomRaw, topRaw);
    uint16_t mx = max(calBottomRaw, topRaw);
    uint16_t travel = mx - mn;
    uint8_t done = calChannel;
    if (travel > 200) {  // sanity: the fader actually traveled
      calMinArr[calChannel] = mn;
      calMaxArr[calChannel] = mx;
      channels[calChannel]->setFaderCalibration(mn, mx);
      snprintf(calMsg[done], sizeof(calMsg[done]), "%u-%u OK", (unsigned)mn, (unsigned)mx);
      sendCalDebug(done, 1, mn, mx);
    } else {
      snprintf(calMsg[done], sizeof(calMsg[done]), "t=%u REJECT", (unsigned)travel);
      sendCalDebug(done, 2, travel, 0);
    }
    calPhase = 0;
    calChannel++;
    showCalScreen(done);  // now shows Done!
    if (calChannel >= NUM_CONNECTED_CHANNELS) {
      saveCalibration();
      exitCalibration(2);
    } else {
      showCalScreen(calChannel);
      sendCalStatus(calChannel, 0);
    }
  }
}

// ---- Incoming: non-blocking packet assembler ----
//
// Bytes are pumped into rxBuf as they arrive; a command is dispatched
// only once its complete packet is present. A truncated packet just
// waits in the buffer instead of desyncing the stream via readBytes
// timeouts. Unknown lead bytes are discarded one at a time (resync).
//
// Exception: CMD_DISPLAY_UPDATE_ICON. Its 8192-byte payload doesn't fit
// any buffer on this chip, so the parser treats the 2-byte header as the
// packet and the handler streams the payload straight to the display.

#define RX_BUF_SIZE 80  // largest buffered packet: DisplayUpdateAppCommand (66 B)

static uint8_t rxBuf[RX_BUF_SIZE];
static uint8_t rxLen = 0;
static uint8_t rxExpected = 0;

// Full packet length (incl. cmd byte) for each command. 0 = unknown.
static uint8_t packetLength(uint8_t cmd) {
  switch (cmd) {
    case CMD_HANDSHAKE_REQUEST:
    case CMD_HANDSHAKE_ACK:
    case CMD_ECHO_UUID:
    case CMD_CALIBRATION_START:
    case CMD_CALIBRATION_CANCEL:
      return 1;
    case CMD_DISPLAY_UPDATE_APP_NAME:
      return sizeof(DisplayUpdateAppCommand);
    case CMD_DISPLAY_UPDATE_APP_VOLUME:
      return sizeof(DisplayUpdateVolumeCommand);
    case CMD_DISPLAY_UPDATE_ICON:
      return 2;  // header only — payload is streamed by the handler
    default:
      if (cmd == 'h' || cmd == 'u') return 1;  // debug shortcuts
      return 0;
  }
}

static void handleIconTransfer(uint8_t ch) {
  // Motors must not run unsupervised during the ~0.75s blocking transfer
  for (uint8_t i = 0; i < NUM_CONNECTED_CHANNELS; i++) channels[i]->stopFader();

  if (!calMode && ch < NUM_CONNECTED_CHANNELS) {
    channels[ch]->receiveIcon(Serial);
  } else {
    // Invalid channel: still consume the payload or the stream desyncs
    uint16_t remaining = 8192;
    uint32_t lastByte = millis();
    while (remaining > 0 && millis() - lastByte < 500) {
      if (Serial.available()) { Serial.read(); remaining--; lastByte = millis(); }
    }
  }
}

static void dispatchPacket() {
  uint8_t cmd = rxBuf[0];

  if (cmd == CMD_HANDSHAKE_REQUEST || cmd == 'h') {
    sendHandshake();
    handshakeComplete = true;
  }
  else if (cmd == CMD_HANDSHAKE_ACK) {
    handshakeComplete = true;  // stop beaconing
  }
  else if (cmd == CMD_ECHO_UUID || cmd == 'u') {
    uint8_t uuid[UUID_SIZE];
    getDeviceUUID(uuid);
    Serial.write(uuid, UUID_SIZE);
  }
  else if (cmd == CMD_DISPLAY_UPDATE_APP_NAME) {
    DisplayUpdateAppCommand c;
    memcpy(&c, rxBuf, sizeof(c));
    c.name[63] = '\0';
    if (!calMode && c.channel < NUM_CONNECTED_CHANNELS) {
      channels[c.channel]->setApp(c.name);
    }
  }
  else if (cmd == CMD_DISPLAY_UPDATE_APP_VOLUME) {
    DisplayUpdateVolumeCommand c;
    memcpy(&c, rxBuf, sizeof(c));
    if (!calMode && c.channel < NUM_CONNECTED_CHANNELS) {
      // Updates the display AND motor-seeks the fader. The fader
      // suppresses touch events during the seek, so this won't echo
      // back to the host as a CMD_FADER_UPDATE.
      channels[c.channel]->setVolume(c.volume);
    }
  }
  else if (cmd == CMD_DISPLAY_UPDATE_ICON) {
    handleIconTransfer(rxBuf[1]);
  }
  else if (cmd == CMD_CALIBRATION_START) {
    startCalibration();
  }
  else if (cmd == CMD_CALIBRATION_CANCEL) {
    cancelCalibration();
  }
}

static void pumpSerial() {
  while (Serial.available() > 0) {
    uint8_t b = Serial.read();

    if (rxLen == 0) {
      // Start of a packet: byte must be a known command
      rxExpected = packetLength(b);
      if (rxExpected == 0) continue;  // unknown byte — discard, resync
    }

    rxBuf[rxLen++] = b;

    if (rxLen >= rxExpected) {
      dispatchPacket();
      rxLen = 0;
      rxExpected = 0;
    }
  }
}

// ---- Arduino ----

void setup() {
  Serial.begin(115200);

  initDeviceID();

  pinMode(BL_PIN, OUTPUT);
  analogWrite(BL_PIN, 200);

  // Keep the Mega in SPI master mode
  pinMode(SS_PIN, OUTPUT);
  digitalWrite(SS_PIN, HIGH);

  // All CS lines high BEFORE any display init — always all 5,
  // even if fewer channels are active, so floating CS lines
  // can't latch stray traffic on the shared bus
  for (uint8_t i = 0; i < NUM_CHANNELS; i++) {
    pinMode(CS_PINS[i], OUTPUT);
    digitalWrite(CS_PINS[i], HIGH);
  }

  for (uint8_t i = 0; i < NUM_CONNECTED_CHANNELS; i++) {
    channels[i] = new Channel(
      i,
      CS_PINS[i], DC_PINS[i], RST_PINS[i],
      ENC_DT[i], ENC_CLK[i], ENC_SW[i],
      MOTOR_A[i], MOTOR_B[i], FADER_PIN[i]
    );
    channels[i]->begin();
    pumpSerial();  // drain anything the host sent during slow display init
  }

  loadCalibration();
}

void loop() {
  static unsigned long lastBeacon = 0;

  // Auto-announce until the desktop app answers
  if (!handshakeComplete && millis() - lastBeacon > 500) {
    sendHandshake();
    lastBeacon = millis();
  }

  pumpSerial();

  if (calMode) {
    runCalibration();
    return;
  }

  // Local hardware always runs (encoders, touch detection,
  // motor seeks, display updates)
  for (uint8_t i = 0; i < NUM_CONNECTED_CHANNELS; i++) {
    Channel* ch = channels[i];
    ch->update();

    pumpSerial();  // drain between channels — display redraws are slow

    // ...but only report to the host once the link is up
    if (!handshakeComplete) continue;

    if (ch->hasFaderChanged()) {
      sendFaderUpdate(i, ch->getVolume());
    }

    if (ch->hasEncoderChanged()) {
      ch->getEncoderDelta();  // consume
      sendFaderUpdate(i, ch->getVolume());
    }

    if (ch->wasButtonPressed()) {
      // TODO: mute toggle / button CMD
    }
  }
}

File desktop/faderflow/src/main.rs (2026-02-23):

mod comms;
mod ui;
mod audio;
mod utils;

use serialport::{self};
use std::io::{Read, Write, BufRead};
use ui::resources::load_icon;
use std::time::Duration;
use std::thread;
use std::sync::{Arc, Mutex};
use iced::application::TitleFn;
use iced::Settings;
use comms::protocol;
use crate::comms::protocol::{
    FaderMessage, HandshakeResponse,
    CMD_FADER_UPDATE, CMD_HANDSHAKE_REQUEST, CMD_HANDSHAKE_ACK, CMD_HANDSHAKE_RESPONSE,
    DisplayUpdateAppCommand, DisplayUpdateVolumeCommand,
    CMD_DISPLAY_UPDATE_APP_NAME, CMD_DISPLAY_UPDATE_APP_VOLUME
};

pub const INIT_WAIT_TIME_MS: u64 = 100;

use ui::app::VolumeApp;

fn main() -> iced::Result {
    iced::application(VolumeApp::new, VolumeApp::update, VolumeApp::view)
        .subscription(VolumeApp::subscription)
        .title("FaderFlow")
        .window(iced::window::Settings {
            icon: Some(load_icon()),
            ..Default::default()
        })
        .run()
}

/*
fn send_app_name(port: &mut dyn SerialPort, channel: u8, name: &str) -> Result<(), Box<dyn std::error::Error>> {
    let mut cmd = DisplayUpdateAppCommand {
        cmd: CMD_DISPLAY_UPDATE_APP_NAME,
        channel,
        name: [0; 64],
    };

    let bytes = name.as_bytes();
    let len = bytes.len().min(63);
    cmd.name[..len].copy_from_slice(&bytes[..len]);

    let bytes = unsafe {
        std::slice::from_raw_parts(&cmd as *const _ as *const u8, std::mem::size_of::<DisplayUpdateAppCommand>())
    };

    port.write_all(bytes)?;
    port.flush()?;

    println!("Sent app name '{}' to channel {}", name, channel);
    Ok(())
}

fn send_volume(port: &mut dyn SerialPort, channel: u8, volume: u8) -> Result<(), Box<dyn std::error::Error>> {
    let cmd = DisplayUpdateVolumeCommand {
        cmd: CMD_DISPLAY_UPDATE_APP_VOLUME,
        channel,
        volume: volume.min(100),
    };

    let bytes = unsafe {
        std::slice::from_raw_parts(&cmd as *const _ as *const u8, std::mem::size_of::<DisplayUpdateVolumeCommand>())
    };
    port.write_all(bytes)?;
    port.flush()?;

    println!("Sent volume {} to channel {}", volume, channel);
    Ok(())
}*/

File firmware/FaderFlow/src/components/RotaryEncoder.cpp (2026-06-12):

//
// Created by Mackan on 2026-02-13.
//

#include "RotaryEncoder.h"

RotaryEncoder::RotaryEncoder(uint8_t pinDT, uint8_t pinCLK, uint8_t pinSW) {
    this->pinDT = pinDT;
    this->pinCLK = pinCLK;
    this->pinSW = pinSW;

    position = 0;
    lastPosition = 0;
    lastStateCLK = LOW;
    buttonState = HIGH;
    lastButtonState = HIGH;
    lastDebounceTime = 0;
    buttonPressed = false;
}

void RotaryEncoder::begin() {
    pinMode(pinDT, INPUT_PULLUP);
    pinMode(pinCLK, INPUT_PULLUP);
    pinMode(pinSW, INPUT_PULLUP);

    lastStateCLK = digitalRead(pinCLK);
}

void RotaryEncoder::update() {
    // Read encoder rotation
    uint8_t currentStateCLK = digitalRead(pinCLK);

    if (currentStateCLK != lastStateCLK && currentStateCLK == HIGH) {
        // CLK changed from LOW to HIGH (detent position)
        if (digitalRead(pinDT) != currentStateCLK) {
            position++; // Clockwise
        } else {
            position--; // Counter-clockwise
        }
    }

    lastStateCLK = currentStateCLK;

    // Read button with debouncing
    bool reading = digitalRead(pinSW);

    if (reading != lastButtonState) {
        lastDebounceTime = millis();
    }

    if ((millis() - lastDebounceTime) > DEBOUNCE_DELAY) {
        if (reading != buttonState) {
            buttonState = reading;

            // Button was pressed (LOW = pressed)
            if (buttonState == LOW) {
                buttonPressed = true;
            }
        }
    }

    lastButtonState = reading;
}

int RotaryEncoder::getDelta() {
    int delta = position - lastPosition;
    lastPosition = position;
    return delta;
}

bool RotaryEncoder::wasPressed() {
    bool pressed = buttonPressed;
    buttonPressed = false; // Clear the flag
    return pressed;
}

void RotaryEncoder::reset() {
    position = 0;
    lastPosition = 0;
    buttonPressed = false;
}

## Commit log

2026-02-07 Restructure project, add mute button
2026-02-11 Add Initial arduino shield file
    [Arduino Shield.kicad_pcb, Arduino Shield.kicad_sch]
2026-02-12 Update shield pcb silkscreen
    [Arduino Shield.kicad_pcb]
2026-02-12 Update pcb, start channel
    [Arduino Shield.kicad_pcb, Arduino Shield.kicad_sch]
2026-02-13 Update main PCB to use 9pin connectors for channels (They need unique RST)
    [Arduino Shield.kicad_pcb, Arduino Shield.kicad_sch]
2026-02-13 Fix gitignore, start icons and channel pcbs
    [Channel.kicad_pcb, Channel.kicad_sch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]
2026-02-13 Make arduino code more structured, start appname and volume sync protocols.
2026-02-16 Update main pcb silkscreen.
    [Arduino Shield.kicad_pcb, Channel.kicad_pcb, Channel.kicad_sch]
2026-02-16 Update the gerbers
    [Arduino Shield.kicad_pcb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]
2026-02-16 Add drills and edge cut gerbers.
    [Arduino Shield-Edge_Cuts.gbr, Arduino Shield-NPTH.drl, Arduino Shield-PTH.drl]
2026-02-16 Silkscreen updates.
    [Arduino Shield-B_Cu.gbr, Arduino Shield-B_Silkscreen.gbr, Arduino Shield-Edge_Cuts.gbr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]
2026-02-18 Start a potential V2 mainboard with teensy
    [Channel-B_Cu.gbr, Channel-B_Mask.gbr, Channel-B_Paste.gbr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]
2026-02-21 Fix up channel pcb
    [Channel-B_Cu.gbr, Channel-B_Mask.gbr, Channel-B_Paste.gbr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]
2026-02-21 Update pcb gerbers,
    [Arduino Shield-B_Cu.gbr, Arduino Shield-B_Silkscreen.gbr, Arduino Shield-Edge_Cuts.gbr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]
2026-02-23 Update pcb gerbers
    [Arduino Shield-B_Courtyard.gbr, Arduino Shield-B_Cu.gbr, Arduino Shield-B_Mask.gbr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]
2026-02-23 Update UI and device handling.
2026-06-12 Get firmware and sofware working better with hardware, in terms of all 5 channels and motorized faders.
    [Arduino Shield-B_Courtyard.gbr, Arduino Shield-B_Cu.gbr, Arduino Shield-B_Mask.gbr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]
2026-06-13 Improve calibration
